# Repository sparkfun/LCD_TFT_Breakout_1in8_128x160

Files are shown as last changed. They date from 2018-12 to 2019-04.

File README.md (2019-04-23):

SparkFun LCD TFT Breakout 1.8" 128x160
========================================

LCD TFT Breakout 1.8" 128x160

[*LCD TFT Breakout 1.8" 128x160 (LCD-15143)*](https://www.sparkfun.com/products/15143)

A 128x160 color (18 bit!) TFT LCD display breakout with 4-wire SPI interface and microSD card holder. You can use this breakout to easily add visual display/interface capabilities to a project as well as all the storage you might need for multimedia files. 

Repository Contents
-------------------

* **/Documentation** - Data sheets, additional product information
* **/Hardware** - Eagle design files (.brd, .sch)
* **/Production** - Production panel files (.brd)

Documentation
--------------
* **[Library (Top Level)](https://github.com/sparkfun/SparkFun_HyperDisplay)** - Arduino library for general control of 2D visual interfaces.
* **[Library (Mid Level)](https://github.com/sparkfun/HyperDisplay_ILI9163C_ArduinoLibrary)** - Arduino library for all ILI9163 drivers (depends on top level).
* **[Library (Bottom Level)](https://github.com/sparkfun/HyperDisplay_KWH018ST01_4WSPI_ArduinoLibrary)** - Arduino library for the display module used in this breakout (depends on mid level).
* **[Hookup Guide](https://learn.sparkfun.com/tutorials/tft-lcd-breakout-18in-128x160-hookup-guide)** - Basic hookup guide for the LCD TFT Breakout 1.8" 128x160.
* **[SparkFun Fritzing repo](https://github.com/sparkfun/Fritzing_Parts)** - Fritzing diagrams for SparkFun products. 
<!-- * **[SparkFun 3D Model repo](https://github.com/sparkfun/3D_Models)** - 3D models of SparkFun products.  -->
<!-- * **[SparkFun Graphical Datasheets](https://github.com/sparkfun/Graphical_Datasheets)** -Graphical Datasheets for various SparkFun products. -->

Product Versions
----------------
* [LCD-15143](https://www.sparkfun.com/products/15143)

License Information
-------------------

This product is _**open source**_! 

Please review the LICENSE.md file for license information. 

If you have any questions or concerns on licensing, please contact technical support on our [SparkFun forums](https://forum.sparkfun.com/viewforum.php?f=152)

Distributed as-is; no warranty is given.

- Your friends at SparkFun.

_<COLLABORATION CREDIT>_

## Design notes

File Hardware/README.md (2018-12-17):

SparkFun <PRODUCT NAME> Design Files
=====================================

The .sch and .brd files hare are Eagle CAD schematic and PCB design files from SparkFun Electronics.
A freeware version of Eagle can be found [here](http://www.cadsoftusa.com/download-eagle/freeware/).

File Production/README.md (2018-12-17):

SparkFun <PRODUCT NAME> Production Files
=========================================

These are the production files SparkFun uses for printing PCBs.

License Information
-------------------
This product is open source! 

The hardware is released under [Creative Commons ShareAlike 4.0 International](https://creativecommons.org/licenses/by-sa/4.0/).

Please use, reuse, and modify these files as you see fit. Please maintain attribution to SparkFun Electronics and release anything derivative under the same license.

Distributed as-is; no warranty is given.

- Your friends at SparkFun.

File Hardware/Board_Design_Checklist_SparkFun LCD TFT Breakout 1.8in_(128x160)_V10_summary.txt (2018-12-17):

1) Are the part libraries consistent with eagle github repo? [NO]
comment: No. I haven't added the display to the libraries because I'm not sure where to put it, besides the part on the board is an FPC connector, not the display itself. I did add the FPC connector under the 40 position connector in the connectors library. Also there is one footprint that is just a custom solder position for the user so I'm not sure if that goes in the library

2) Have you verified that the BOM in Sparkle is accurate (also checking for PROD_ID, NAME, VALUE, PREFIX)? [NO]
comment: No Sparkle product yet... 

3) Do V-Scored edges have a 50 mil border free of pads and parts (to prevent cracking on separation)? [NO]
comment: Nearly... but I want the FPC connector to be right up at the edge of one vscore so that one violates this rule

4) Are all QFN components with 6 or more leads 75 percent pasted on lead pads? (May be contended depending on performance) [NO]
comment: They're closer to 80-90% pasted

5) Is there a correct version number in the copper (aligned properly with the edge of the PCB)? [NO]
comment: I couldn't fit it right on the edge, but it's close ish

6) Are all PTHs (aka connectors) clearly labeled with their purpose on both sides of the board? [NO]
comment: No, bottom side is unlabeled due to space constraints

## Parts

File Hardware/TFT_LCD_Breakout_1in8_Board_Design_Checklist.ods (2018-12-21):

SECTION | CHECK | STATUS | DEPENDANCY | CORRECT ANSWER | USER | USER-ANSWER | COMMENT | WIKI_LINK
Macro | is_revision | 0
Macro | has_pth | 0
Macro | has_i2c | 0
Macro | has_SPI | 0
Macro | has_1x6_ftdi_header | 0
Macro | has_jumpers | 0
Macro | has_leds | 0
Macro | has_vreg | 0
Macro | has_QFN | 0
Macro | has_SS | 0
Macro | has_multi_sheet | 0
Macro | is_kit | 0
Macro | has_serial | 0
Macro | is_4layer | 0
Macro | has_milling | 0
Macro | has_switchorbutton | 0
Macro | has_collaboration | 0
General | Are the part libraries consistent with eagle github repo? | YES |  | YES
Schematic | Is the proper frame with CC attribution used? | YES |  | YES
Schematic | Are all schematic objects inside the frame? | YES |  | YES
Schematic | Is there a SparkFun Logo? | YES |  | YES
Schematic | Is there an OSHW logo? | YES |  | YES
Schematic | Is proper attribution given to the original designer? | YES |  | YES
Schematic | Is "Revised by: " and the reviser's name present? | N/A | 2 | YES
Schematic | Are NET labels the correct FLAG type? | YES |  | YES
Schematic | Have all nets been drawn straight out from pin connections at least one grid space? | YES |  | YES
Schematic | Are all net lines 0.006 inch? | YES |  | YES
Schematic | Are there any 4-way junctions? | NO |  | NO
Schematic | Are junction dots used for all 3-wire connections? | YES |  | YES
Schematic | Are the fiducials in the lower right corner? | YES |  | YES
Schematic | Are the standoffs in the lower right corner? | YES |  | YES
Schematic | Are dashed grey lines ('info' eagle layer 97) used to clearly separate different areas? | YES |  | YES
Schematic | Is the version number correct? | YES |  | YES
Schematic | Is the version number included on all sheets? | YES | 12 | YES
Schematic | Do all GND connections use the GND symbol (oriented downward)? | YES |  | YES
Schematic | Do all VCC connections use the VCC symbol (oriented upward)? | YES |  | YES
Schematic | Is the VCC range clearly labeled? | YES |  | YES
Schematic | Are any jumpers labeled clearly by their function and possible settings? | YES | 7 | YES
Schematic | Are any appropriate warnings (voltage conversion, sensitive I/O) labeled? | YES |  | YES
Schematic | Are any notes of two versions of the board in the schematic (3.3V regulator vs 5V regulator)? | N/A |  | YES
Schematic | Do any part names have '/.~' in them? (Multiple sheets) | NO | 12 | NO
Schematic | Have you verified that the BOM in Sparkle is accurate (also checking for PROD_ID, NAME, VALUE, PREFIX)? | YES |  | YES
Schematic | Do any parts have unnecessary values (Eagle has autoset the package as the value)? | NO |  | NO
Schematic | Regarding the voltage regulator, is the input on the LEFT, and the output on the RIGHT? | YES | 9 | YES
Schematic | Is the I2C address in the schematic? | N/A | 4 | YES
Schematic | Is the I2C pin order correct (GND/VCC/SDA/CLK) and did you consider using a Qwiic connector? | N/A | 4 | YES |  |  |  | https://wiki.sparkfun.com/index.php?title=Eagle_Rules#Pin_Out.2FConnection_Orientation
Schematic | Is the I2C pull-up resistor isolation jumper present? | N/A | 4 | YES |  |  |  | https://wiki.sparkfun.com/index.php?title=Eagle_Rules#Component_Placement
Schematic | Is the SPI pull-up resistor for Chip Select present? | YES | 5 | YES |  |  |  | https://wiki.sparkfun.com/index.php?title=Eagle_Rules#Component_Placement
Schematic | Is the MISO tri-state buffer included? | NO | 5 | YES |  |  |  | https://wiki.sparkfun.com/index.php?title=Eagle_Rules#Component_Placement
Board | If this is a Qwiic board, does it follow the design guidelines for Qwiic boards in the Wiki? | N/A | 4 | YES |  |  |  | https://wiki.sparkfun.com/index.php?title=Qwiic_Standard
Board | If this board is not branded as a Qwicc board, but contains a Qwiic connector, is the connector labeled with “QWIIC” text silk? | N/A | 4
Board | Are the inner layers on the correct eagle layers? (2 and 15) | N/A | 15 | YES |  |  |  | https://wiki.sparkfun.com/index.php?title=Eagle_Rules#Board_Creation.2C_Outline
Board | Does your 4 layer board include '1' '2' '3' '4' in the copper of each layer? | N/A | 15 | YES |  |  |  | https://wiki.sparkfun.com/index.php?title=Eagle_Rules#Board_Creation.2C_Outline
Board | Is the bottom left corner board dimensions at 0,0? | YES |  | YES |  |  |  | https://wiki.sparkfun.com/index.php?title=Eagle_Rules#Board_Creation.2C_Outline
Board | Is the board dimension outline correct thickness? (0.008 inch) | YES |  | YES |  |  |  | https://wiki.sparkfun.com/index.php?title=Eagle_Rules#Board_Creation.2C_Outline
Board | If this requires very precise dimensions (e.g. USB stick), did you consider GP's tolerances? (dimension=5mils, Vscore=10mils) | N/A |  |  |  |  |  | https://wiki.sparkfun.com/index.php?title=Eagle_Rules#Fab_house_Tolerances
Board | Are 0.1 inch headers lined up on 0.1 inch grid? | YES |  | YES |  |  |  | https://wiki.sparkfun.com/index.php?title=Eagle_Rules#Board_Creation.2C_Outline
Board | Are opposing 0.1 inch headers spaced to fit into a breadboard? | N/A |  | YES |  |  |  | https://wiki.sparkfun.com/index.php?title=Eagle_Rules#Board_Creation.2C_Outline
Board | Do all testpoints have a separation of at least 0.1 inch (preferably placed on a 0.05 inch grid)? | YES |  | YES |  |  |  | https://wiki.sparkfun.com/index.php?title=Eagle_Rules#Board_Creation.2C_Outline
Board | Does the board have standoffs? | YES |  | YES |  |  |  | https://wiki.sparkfun.com/index.php?title=Eagle_Rules#Board_Creation.2C_Outline
Board | Can standoffs/screws be used clear of other parts? | YES |  | YES |  |  |  | https://wiki.sparkfun.com/index.php?title=Eagle_Rules#Board_Creation.2C_Outline
Board | Is the FTDI connector accessible (do neighboring parts allow enough space to clear each side)? | N/A | 6 | YES |  |  |  | https://wiki.sparkfun.com/index.php?title=Eagle_Rules#Pin_Out.2FConnection_Orientation
Board | Is the FTDI connector oriented so the FTDI breakout can be slid on properly (IC side up, header side down)? | N/A | 6 | YES |  |  |  | https://wiki.sparkfun.com/index.php?title=Eagle_Rules#Pin_Out.2FConnection_Orientation
Board | Are vias tented correctly? | YES |  | YES |  |  |  | https://wiki.sparkfun.com/index.php?title=Eagle_Rules#Trace_Routing.2C_Polygon_Pours.2C_and_Vias
Board | If possible, are all overhanging parts on the same edge of the board (this helps with panelization)? | N/A |  | YES |  |  |  | https://wiki.sparkfun.com/index.php?title=Eagle_Rules#Pin_Out.2FConnection_Orientation
Board | If this design requires special ordering or production assembly instructions, have the symbols/packages been added with notes? (PCB thickness, humidity sensitivity, etc.) | YES |  | YES
Board | Are any vias intended to be used as PTH headers (they shouldn't be)? | NO |  | NO |  |  |  | https://wiki.sparkfun.com/index.php?title=Eagle_Rules#Trace_Routing.2C_Polygon_Pours.2C_and_Vias
Board | Is the LED color standard followed? (red for power, blue for STAT, green for TX, yellow for RX) | YES | 8 | YES |  |  |  | https://wiki.sparkfun.com/index.php?title=Eagle_Rules#Component_Placement
Board | Do parts that need selective solder have a planned nozzle path on layer 48? (valid widths: 0.178", 0,263", 0.354") | N/A | 11 | YES |  |  |  | https://wiki.sparkfun.com/index.php?title=Eagle_Rules#Selective_Soldering
Board | As best as possible, do all SMD pads have only 1 trace entering the pad? | YES |  | YES |  |  |  | https://wiki.sparkfun.com/index.php?title=Eagle_Rules#PCB_Layout
Board | Are there any natural bridges on SMT components? | NO |  | NO |  |  |  | https://wiki.sparkfun.com/index.php?title=Eagle_Rules#PCB_Layout
Board | Do V-Scored edges have a 50 mil border free of pads and parts (to prevent cracking on separation)? | YES |  | YES
Board | Is the direction of TX/RX serial connections correct? | N/A | 14 | YES
Board | Are the TX/RX pins of the FTDI properly connected? | N/A | 6 | YES
Board | Is trace routing up to spec? (to/from center-points, straight lines, 45 angles, 'T' intersections, no right angles or acid traps) | YES |  | YES |  |  |  | https://wiki.sparkfun.com/index.php?title=Eagle_Rules#PCB_Layout
Board | For thermal considerations, are traces routed away from the component, with symmetrical routing? | YES | 10 | YES
Board | Do all footprints pass 1:1 check? (Applies mostly to new components) | YES |  | YES
Board | Are all QFN components with 6 or more leads 75 percent pasted on lead pads? (May be contended depending on performance) | YES | 10 | YES |  |  |  | https://wiki.sparkfun.com/index.php?title=Eagle_Rules#Footprints.2FPackages
Board | Are center pad cream apertures properly reduced? (50-75% paste is good) | N/A | 10 | YES |  |  |  | https://wiki.sparkfun.com/index.php?title=Eagle_Rules#Footprints.2FPackages
Board | Is there solder mask between pads on of 11 mil separation and greater? | NO |  | YES |  |  |  | https://wiki.sparkfun.com/index.php?title=Eagle_Rules#Fab_house_Tolerances
Board | Is there a correct version number in the copper (aligned properly with the edge of the PCB)? | YES |  | YES
Board | Are there fiducials on both the TOP and BOTTOM of the board? | YES |  | YES
Board | Does it pass DRC with top/bottom keepout layers on? | YES |  | YES
Board | If there are any DRC errors, have they all been approved? | YES |  | YES
Board | Are there airwires after ratsnest? | NO |  | NO
Board | Are all KIT PTH parts on the correct side with correct masking (e.g. the TSTOP or BSTOP expose the correct side) | N/A | 13 | YES
Documentation | Is there a note for a 4-layer board (on tDOCU)? | N/A | 15 | YES
Documentation | Do all packages have NAME and VALUE? | YES |  | YES
Documentation | Is there a note for a board thickness other than 0.63 inch? | N/A
Documentation | Are measurements included for outer dimension and standoffs (Eagle layer 47)? | YES |  | YES
Documentation | Are the board dimensions on 0.05 inch or 0.01 inch grid? | YES |  | YES
Documentation | Are routed-out areas labeled 'ROUTE OUT' (on dimension)? | YES | 16 | YES
Documentation | Is the CC/Design By included in tDocu? | YES |  | YES
Documentation | Is the designer name included in tDocu? | YES |  | YES
Documentation | Is 'Revised by:' and 'Revisor Name' included in tDocu? | N/A | 2 | YES
Silkscreen/Labeling | Is the name of the board on the board? | YES |  | YES |  |  |  | https://wiki.sparkfun.com/index.php?title=Eagle_Rules#PCB_Silk
Silkscreen/Labeling | Do all footprints have 0.008 inch silk footprint? | YES |  | YES
Silkscreen/Labeling | Are all LEDs labeled with their purpose? | YES | 8 | YES
Silkscreen/Labeling | Are all PTHs (aka connectors) clearly labeled with their purpose on both sides of the board? | YES |  | YES
Silkscreen/Labeling | Are battery terminals labeled +/- correctly? | N/A |  | YES
Silkscreen/Labeling | Are all jumpers labeled? | YES | 7 | YES
Silkscreen/Labeling | If it is a 3-way jumper, is there a label on each side of the jumper? | N/A | 7 | YES
Silkscreen/Labeling | Are all switches/buttons labeled properly? | N/A | 17 | YES
Silkscreen/Labeling | Are active low pins labeled clearly? | YES |  | YES
Silkscreen/Labeling | Are all labels lined up properly? | YES |  | YES
Silkscreen/Labeling | Is all text at least 0.032 inch, 15 percent radio, and vector? | YES |  | YES
Silkscreen/Labeling | Does the FTDI connector have BLK/GRN labeled correctly? | N/A | 6 | YES
Silkscreen/Labeling | Do all components have polarity or pin 1 labeled? | YES |  | YES
Silkscreen/Labeling | Is the polarity label outside of the package for visibility after part population? | YES |  | YES
Silkscreen/Labeling | Are there check labels for different versions of the board (3.3V vs 5V)? | N/A |  | YES
Silkscreen/Labeling | Is the SparkFun Logo on the board? | YES |  | YES
Silkscreen/Labeling | Is the OSHW logo on the board? | YES |  | YES
Silkscreen/Labeling | Is the firmware opensource? If not, did you omit the OSHW Logo? | YES | 18 | YES
Silkscreen/Labeling | Is any silkscreen overlaid on vias? | YES |  | NO
Silkscreen/Labeling | Is there a URL for any kits or unique boards? | N/A
Special | Are dimension lines properly spaced for V-scoring (lines on a 0.020” center-to-center spacing)? | YES
Special | On white solder mask pcbs, is there any solder mask between leads on large SMT components? | N/A
Special | Are axes labeled correctly? | N/A
Special | Are there warning labels for high voltage areas? | N/A
END | Thanks for flying with us. Have a great day!! | NO

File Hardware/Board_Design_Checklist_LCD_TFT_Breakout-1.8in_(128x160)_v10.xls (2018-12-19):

SECTION | CHECK | STATUS | DEPENDANCY | CORRECT ANSWER | USER | USER-ANSWER | COMMENT | WIKI_LINK
Macro | is_revision | 0
Macro | has_pth | 1
Macro | has_i2c | 0
Macro | has_SPI | 1
Macro | has_1x6_ftdi_header | 0
Macro | has_jumpers | 0
Macro | has_leds | 0
Macro | has_vreg | 0
Macro | has_QFN | 1
Macro | has_SS | 0
Macro | has_multi_sheet | 0
Macro | is_kit | 0
Macro | has_serial | 0
Macro | is_4layer | 0
Macro | has_milling | 1
Macro | has_switchorbutton | 0
Macro | has_collaboration | 0
General | Are the part libraries consistent with eagle github repo? |  |  | YES | owen.lyke | YES
Schematic | Is the proper frame with CC attribution used? |  |  | YES | owen.lyke | YES
Schematic | Are all schematic objects inside the frame? |  |  | YES | owen.lyke | YES
Schematic | Is there a SparkFun Logo? |  |  | YES | owen.lyke | YES
Schematic | Is there an OSHW logo? |  |  | YES | owen.lyke | YES
Schematic | Is proper attribution given to the original designer? |  |  | YES | owen.lyke | YES
Schematic | Is "Revised by: " and the reviser's name present? |  | 2 | YES | owen.lyke | *n/a*
Schematic | Are NET labels the correct FLAG type? |  |  | YES | owen.lyke | YES
Schematic | Have all nets been drawn straight out from pin connections at least one grid space? |  |  | YES | owen.lyke | YES
Schematic | Are all net lines 0.006 inch? |  |  | YES | owen.lyke | YES
Schematic | Are there any 4-way junctions? |  |  | NO | owen.lyke | NO
Schematic | Are junction dots used for all 3-wire connections? |  |  | YES | owen.lyke | YES
Schematic | Are the fiducials in the lower right corner? |  |  | YES | owen.lyke | YES
Schematic | Are the standoffs in the lower right corner? |  |  | YES | owen.lyke | YES
Schematic | Are dashed grey lines ('info' eagle layer 97) used to clearly separate different areas? |  |  | YES | owen.lyke | YES
Schematic | Is the version number correct? |  |  | YES | owen.lyke | YES | Yes. Changed to v03 since this is now a prototype and there were 2 protos before with SparkX
Schematic | Is the version number included on all sheets? |  | 12 | YES | owen.lyke | *n/a*
Schematic | Do all GND connections use the GND symbol (oriented downward)? |  |  | YES | owen.lyke | YES
Schematic | Do all VCC connections use the VCC symbol (oriented upward)? |  |  | YES | owen.lyke | YES
Schematic | Is the VCC range clearly labeled? |  |  | YES | owen.lyke | YES
Schematic | Are any jumpers labeled clearly by their function and possible settings? |  | 7 | YES | owen.lyke | *n/a*
Schematic | Are any appropriate warnings (voltage conversion, sensitive I/O) labeled? |  |  | YES | owen.lyke | n/a
Schematic | Are any notes of two versions of the board in the schematic (3.3V regulator vs 5V regulator)? |  |  | YES | owen.lyke | n/a
Schematic | Do any part names have '/.~' in them? (Multiple sheets) |  | 12 | NO | owen.lyke | *n/a*
Schematic | Have you verified that the BOM in Sparkle is accurate (also checking for PROD_ID, NAME, VALUE, PREFIX)? |  |  | YES | owen.lyke | YES
Schematic | Do any parts have unnecessary values (Eagle has autoset the package as the value)? |  |  | NO | owen.lyke | NO
Schematic | Regarding the voltage regulator, is the input on the LEFT, and the output on the RIGHT? |  | 9 | YES | owen.lyke | *n/a*
Schematic | Is the I2C address in the schematic? |  | 4 | YES | owen.lyke | *n/a*
Schematic | Is the I2C pin order correct (GND/VCC/SDA/CLK) and did you consider using a Qwiic connector? |  | 4 | YES | owen.lyke | *n/a* |  | https://wiki.sparkfun.com/index.php?title=Eagle_Rules#Pin_Out.2FConnection_Orientation
Schematic | Is the I2C pull-up resistor isolation jumper present? |  | 4 | YES | owen.lyke | *n/a* |  | https://wiki.sparkfun.com/index.php?title=Eagle_Rules#Component_Placement
Schematic | Is the SPI pull-up resistor for Chip Select present? |  | 5 | YES | owen.lyke | YES |  | https://wiki.sparkfun.com/index.php?title=Eagle_Rules#Component_Placement
Schematic | Is the MISO tri-state buffer included? |  | 5 | YES | owen.lyke | NO |  | https://wiki.sparkfun.com/index.php?title=Eagle_Rules#Component_Placement
Board | If this is a Qwiic board, does it follow the design guidelines for Qwiic boards in the Wiki? |  | 4 | YES | owen.lyke | *n/a* |  | https://wiki.sparkfun.com/index.php?title=Qwiic_Standard
Board | If this board is not branded as a Qwicc board, but contains a Qwiic connector, is the connector labeled with “QWIIC” text silk? |  | 4 |  | owen.lyke | NO
Board | Are the inner layers on the correct eagle layers? (2 and 15) |  | 15 | YES | owen.lyke | *n/a* |  | https://wiki.sparkfun.com/index.php?title=Eagle_Rules#Board_Creation.2C_Outline
Board | Does your 4 layer board include '1' '2' '3' '4' in the copper of each layer? |  | 15 | YES | owen.lyke | *n/a* |  | https://wiki.sparkfun.com/index.php?title=Eagle_Rules#Board_Creation.2C_Outline
Board | Is the bottom left corner board dimensions at 0,0? |  |  | YES | owen.lyke | YES |  | https://wiki.sparkfun.com/index.php?title=Eagle_Rules#Board_Creation.2C_Outline
Board | Is the board dimension outline correct thickness? (0.008 inch) |  |  | YES | owen.lyke | YES |  | https://wiki.sparkfun.com/index.php?title=Eagle_Rules#Board_Creation.2C_Outline
Board | If this requires very precise dimensions (e.g. USB stick), did you consider GP's tolerances? (dimension=5mils, Vscore=10mils) |  |  |  | owen.lyke | n/a |  | https://wiki.sparkfun.com/index.php?title=Eagle_Rules#Fab_house_Tolerances
Board | Are 0.1 inch headers lined up on 0.1 inch grid? |  |  | YES | owen.lyke | YES |  | https://wiki.sparkfun.com/index.php?title=Eagle_Rules#Board_Creation.2C_Outline
Board | Are opposing 0.1 inch headers spaced to fit into a breadboard? |  |  | YES | owen.lyke | n/a |  | https://wiki.sparkfun.com/index.php?title=Eagle_Rules#Board_Creation.2C_Outline
Board | Do all testpoints have a separation of at least 0.1 inch (preferably placed on a 0.05 inch grid)? |  |  | YES | owen.lyke | n/a |  | https://wiki.sparkfun.com/index.php?title=Eagle_Rules#Board_Creation.2C_Outline
Board | Does the board have standoffs? |  |  | YES | owen.lyke | YES |  | https://wiki.sparkfun.com/index.php?title=Eagle_Rules#Board_Creation.2C_Outline
Board | Can standoffs/screws be used clear of other parts? |  |  | YES | owen.lyke | YES |  | https://wiki.sparkfun.com/index.php?title=Eagle_Rules#Board_Creation.2C_Outline
Board | Is the FTDI connector accessible (do neighboring parts allow enough space to clear each side)? |  | 6 | YES | owen.lyke | *n/a* |  | https://wiki.sparkfun.com/index.php?title=Eagle_Rules#Pin_Out.2FConnection_Orientation
Board | Is the FTDI connector oriented so the FTDI breakout can be slid on properly (IC side up, header side down)? |  | 6 | YES | owen.lyke | *n/a* |  | https://wiki.sparkfun.com/index.php?title=Eagle_Rules#Pin_Out.2FConnection_Orientation
Board | Are vias tented correctly? |  |  | YES | owen.lyke | YES |  | https://wiki.sparkfun.com/index.php?title=Eagle_Rules#Trace_Routing.2C_Polygon_Pours.2C_and_Vias
Board | If possible, are all overhanging parts on the same edge of the board (this helps with panelization)? |  |  | YES | owen.lyke | YES |  | https://wiki.sparkfun.com/index.php?title=Eagle_Rules#Pin_Out.2FConnection_Orientation
Board | If this design requires special ordering or production assembly instructions, have the symbols/packages been added with notes? (PCB thickness, humidity sensitivity, etc.) |  |  | YES | owen.lyke | YES
Board | Are any vias intended to be used as PTH headers (they shouldn't be)? |  |  | NO | owen.lyke | NO |  | https://wiki.sparkfun.com/index.php?title=Eagle_Rules#Trace_Routing.2C_Polygon_Pours.2C_and_Vias
Board | Is the LED color standard followed? (red for power, blue for STAT, green for TX, yellow for RX) |  | 8 | YES | owen.lyke | *n/a* |  | https://wiki.sparkfun.com/index.php?title=Eagle_Rules#Component_Placement
Board | Do parts that need selective solder have a planned nozzle path on layer 48? (valid widths: 0.178", 0,263", 0.354") |  | 11 | YES | owen.lyke | *n/a* |  | https://wiki.sparkfun.com/index.php?title=Eagle_Rules#Selective_Soldering
Board | As best as possible, do all SMD pads have only 1 trace entering the pad? |  |  | YES | owen.lyke | YES |  | https://wiki.sparkfun.com/index.php?title=Eagle_Rules#PCB_Layout
Board | Are there any natural bridges on SMT components? |  |  | NO | owen.lyke | NO |  | https://wiki.sparkfun.com/index.php?title=Eagle_Rules#PCB_Layout
Board | Do V-Scored edges have a 50 mil border free of pads and parts (to prevent cracking on separation)? |  |  | YES | owen.lyke | NO | No, but it is a feature not a bug. The FPC connector is placed so that after the user breaks away half the board it will be on the edge
Board | Is the direction of TX/RX serial connections correct? |  | 14 | YES | owen.lyke | *n/a*
Board | Are the TX/RX pins of the FTDI properly connected? |  | 6 | YES | owen.lyke | *n/a*
Board | Is trace routing up to spec? (to/from center-points, straight lines, 45 angles, 'T' intersections, no right angles or acid traps) |  |  | YES | owen.lyke | YES |  | https://wiki.sparkfun.com/index.php?title=Eagle_Rules#PCB_Layout
Board | For thermal considerations, are traces routed away from the component, with symmetrical routing? |  | 10 | YES | owen.lyke | YES
Board | Do all footprints pass 1:1 check? (Applies mostly to new components) |  |  | YES | owen.lyke | YES
Board | Are all QFN components with 6 or more leads 75 percent pasted on lead pads? (May be contended depending on performance) |  | 10 | YES | owen.lyke | NO | No, txb0108 is more like 80-90% pasted. But it is tested | https://wiki.sparkfun.com/index.php?title=Eagle_Rules#Footprints.2FPackages
Board | Are center pad cream apertures properly reduced? (50-75% paste is good) |  | 10 | YES | owen.lyke | n/a |  | https://wiki.sparkfun.com/index.php?title=Eagle_Rules#Footprints.2FPackages
Board | Is there solder mask between pads on of 11 mil separation and greater? |  |  | YES | owen.lyke | YES |  | https://wiki.sparkfun.com/index.php?title=Eagle_Rules#Fab_house_Tolerances
Board | Is there a correct version number in the copper (aligned properly with the edge of the PCB)? |  |  | YES | owen.lyke | YES
Board | Are there fiducials on both the TOP and BOTTOM of the board? |  |  | YES | owen.lyke | YES
Board | Does it pass DRC with top/bottom keepout layers on? |  |  | YES | owen.lyke | YES
Board | If there are any DRC errors, have they all been approved? |  |  | YES | owen.lyke | YES | Yes, approved some stubs (used to connect GND beyond pour), overlaps (jumper w trace)
Board | Are there airwires after ratsnest? |  |  | NO | owen.lyke | NO
Board | Are all KIT PTH parts on the correct side with correct masking (e.g. the TSTOP or BSTOP expose the correct side) |  | 13 | YES | owen.lyke | *n/a*
Documentation | Is there a note for a 4-layer board (on tDOCU)? |  | 15 | YES | owen.lyke | *n/a*
Documentation | Do all packages have NAME and VALUE? |  |  | YES | owen.lyke | YES
Documentation | Is there a note for a board thickness other than 0.63 inch? |  |  |  | owen.lyke | n/a
Documentation | Are measurements included for outer dimension and standoffs (Eagle layer 47)? |  |  | YES | owen.lyke | YES
Documentation | Are the board dimensions on 0.05 inch or 0.01 inch grid? |  |  | YES | owen.lyke | YES
Documentation | Are routed-out areas labeled 'ROUTE OUT' (on dimension)? |  | 16 | YES | owen.lyke | YES
Documentation | Is the CC/Design By included in tDocu? |  |  | YES | owen.lyke | YES
Documentation | Is the designer name included in tDocu? |  |  | YES | owen.lyke | YES
Documentation | Is 'Revised by:' and 'Revisor Name' included in tDocu? |  | 2 | YES | owen.lyke | *n/a*
Silkscreen/Labeling | Is the name of the board on the board? |  |  | YES | owen.lyke | YES |  | https://wiki.sparkfun.com/index.php?title=Eagle_Rules#PCB_Silk
Silkscreen/Labeling | Do all footprints have 0.008 inch silk footprint? |  |  | YES | owen.lyke | YES
Silkscreen/Labeling | Are all LEDs labeled with their purpose? |  | 8 | YES | owen.lyke | *n/a*
Silkscreen/Labeling | Are all PTHs (aka connectors) clearly labeled with their purpose on both sides of the board? |  |  | YES | owen.lyke | YES
Silkscreen/Labeling | Are battery terminals labeled +/- correctly? |  |  | YES | owen.lyke | n/a
Silkscreen/Labeling | Are all jumpers labeled? |  | 7 | YES | owen.lyke | *n/a*
Silkscreen/Labeling | If it is a 3-way jumper, is there a label on each side of the jumper? |  | 7 | YES | owen.lyke | *n/a*
Silkscreen/Labeling | Are all switches/buttons labeled properly? |  | 17 | YES | owen.lyke | *n/a*
Silkscreen/Labeling | Are active low pins labeled clearly? |  |  | YES | owen.lyke | YES
Silkscreen/Labeling | Are all labels lined up properly? |  |  | YES | owen.lyke | YES
Silkscreen/Labeling | Is all text at least 0.032 inch, 15 percent radio, and vector? |  |  | YES | owen.lyke | YES
Silkscreen/Labeling | Does the FTDI connector have BLK/GRN labeled correctly? |  | 6 | YES | owen.lyke | *n/a*
Silkscreen/Labeling | Do all components have polarity or pin 1 labeled? |  |  | YES | owen.lyke | YES
Silkscreen/Labeling | Is the polarity label outside of the package for visibility after part population? |  |  | YES | owen.lyke | YES
Silkscreen/Labeling | Are there check labels for different versions of the board (3.3V vs 5V)? |  |  | YES | owen.lyke | n/a
Silkscreen/Labeling | Is the SparkFun Logo on the board? |  |  | YES | owen.lyke | YES
Silkscreen/Labeling | Is the OSHW logo on the board? |  |  | YES | owen.lyke | YES
Silkscreen/Labeling | Is the firmware opensource? If not, did you omit the OSHW Logo? |  | 18 | YES | owen.lyke | *n/a*
Silkscreen/Labeling | Is any silkscreen overlaid on vias? |  |  | NO | owen.lyke | YES
Silkscreen/Labeling | Is there a URL for any kits or unique boards? |  |  |  | owen.lyke | n/a
Special | Are dimension lines properly spaced for V-scoring (lines on a 0.020” center-to-center spacing)? |  |  |  | owen.lyke | YES
Special | On white solder mask pcbs, is there any solder mask between leads on large SMT components? |  |  |  | owen.lyke | n/a
Special | Are axes labeled correctly? |  |  |  | owen.lyke | n/a
Special | Are there warning labels for high voltage areas? |  |  |  | owen.lyke | n/a
END | Thanks for flying with us. Have a great day!! |  |  |  | owen.lyke | NO

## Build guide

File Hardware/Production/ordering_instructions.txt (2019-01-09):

panel size, 91x194mm
PCB thickness, 1.6mm
number of layers, 2
soldermask color, Red
silkscreen color, White
oz copper, 1oz
finish, HASL lead free
stencils, none
pcs per panel, 6

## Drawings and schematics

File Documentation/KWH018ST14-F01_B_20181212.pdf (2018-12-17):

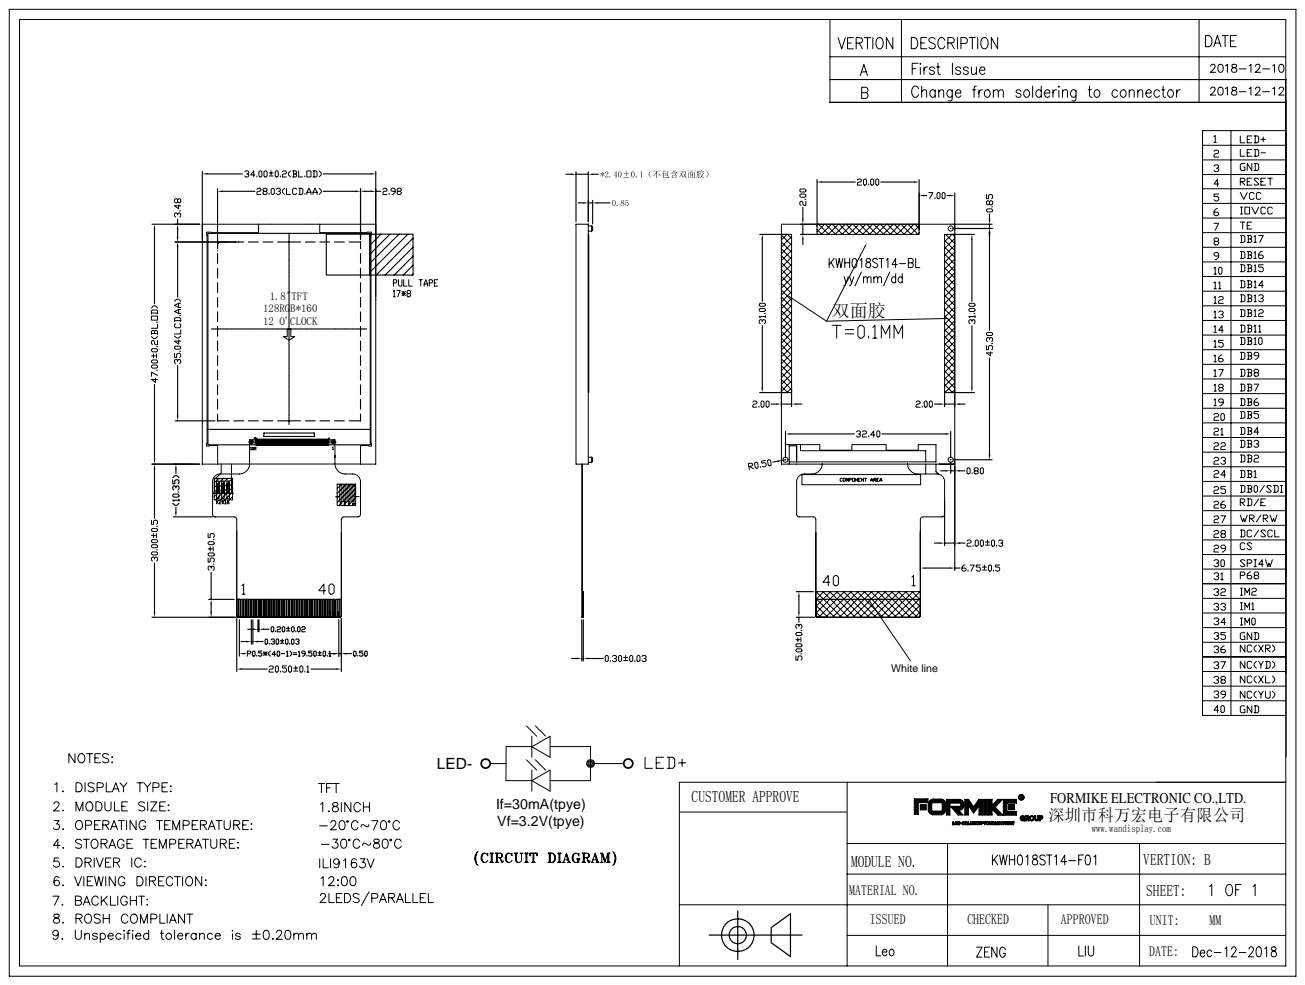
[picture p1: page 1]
VERTION: B; SHEET:; UNIT:; DATE:; CUSTOMER APPROVE; ISSUED; CHECKED; MODULE NO.; APPROVED; MATERIAL NO.; LED-; 1.8"TFT 128RGB*160 12 O'CLOCK; 双面胶; If=30mA(tpye); Vf=3.2V(tpye); www.wandisplay.com 深圳市科万宏电子有限公司; White line

FORMIKE ELECTRONIC CO.,LTD.

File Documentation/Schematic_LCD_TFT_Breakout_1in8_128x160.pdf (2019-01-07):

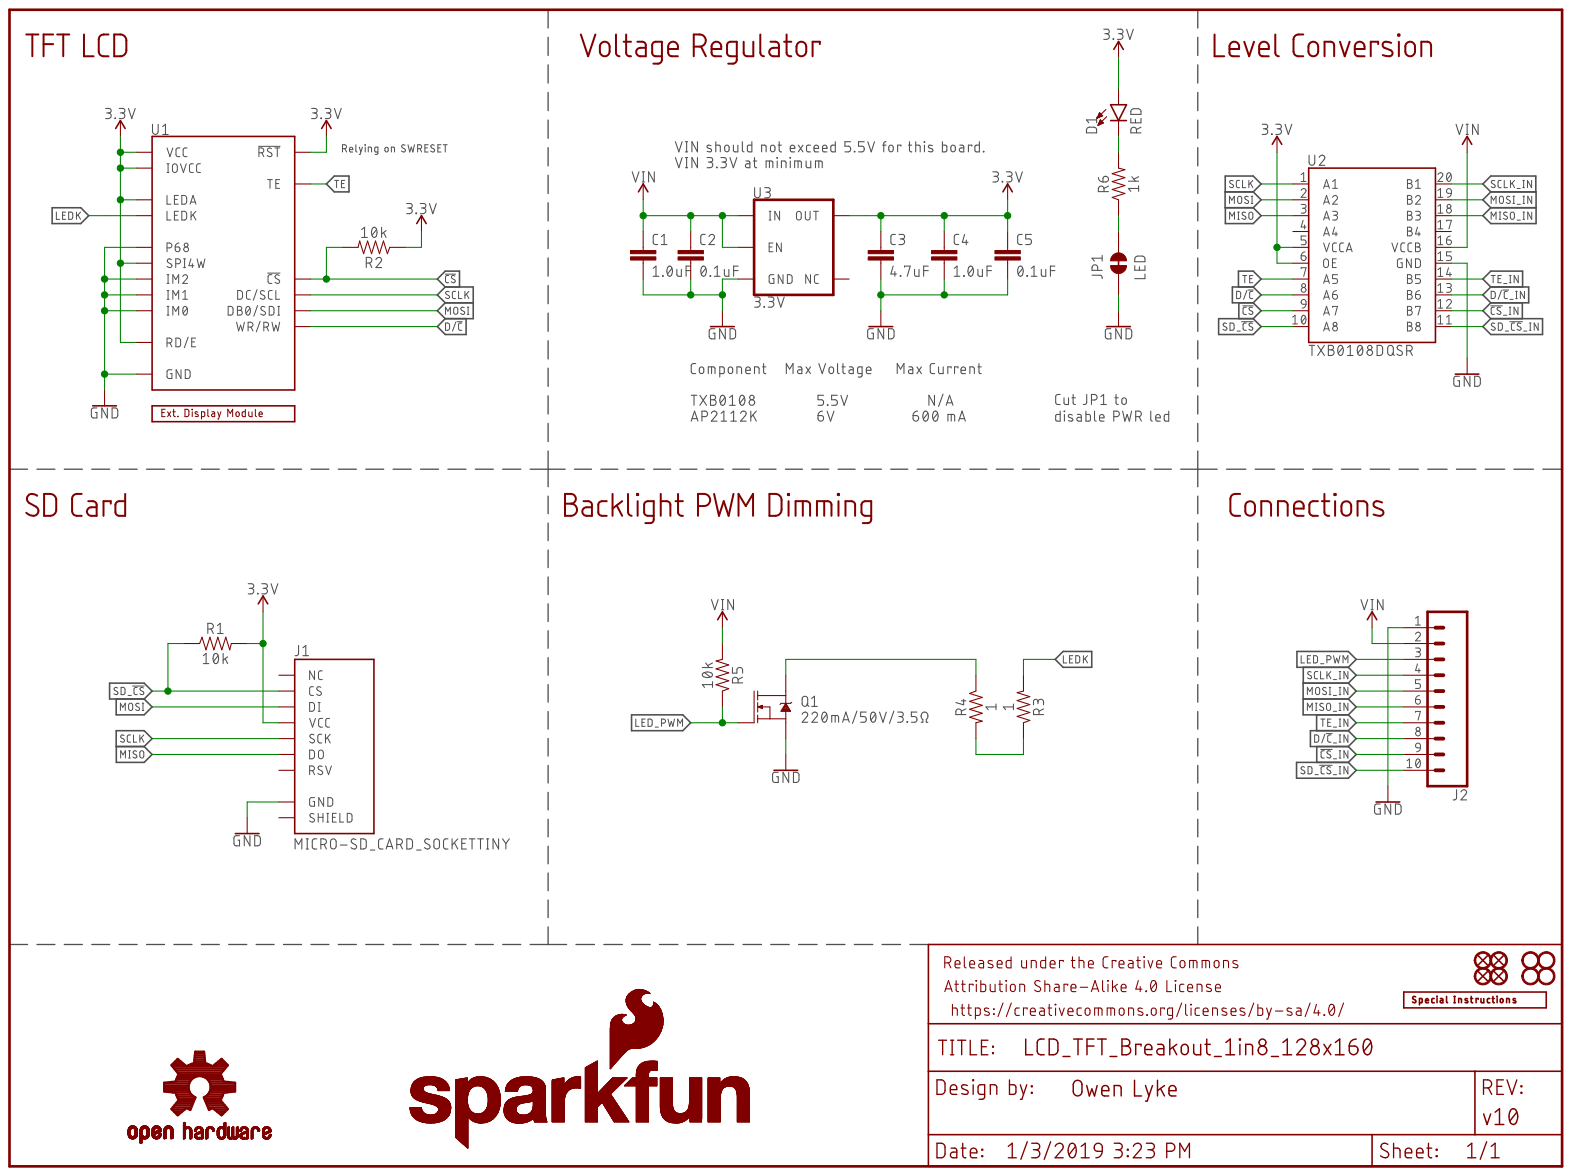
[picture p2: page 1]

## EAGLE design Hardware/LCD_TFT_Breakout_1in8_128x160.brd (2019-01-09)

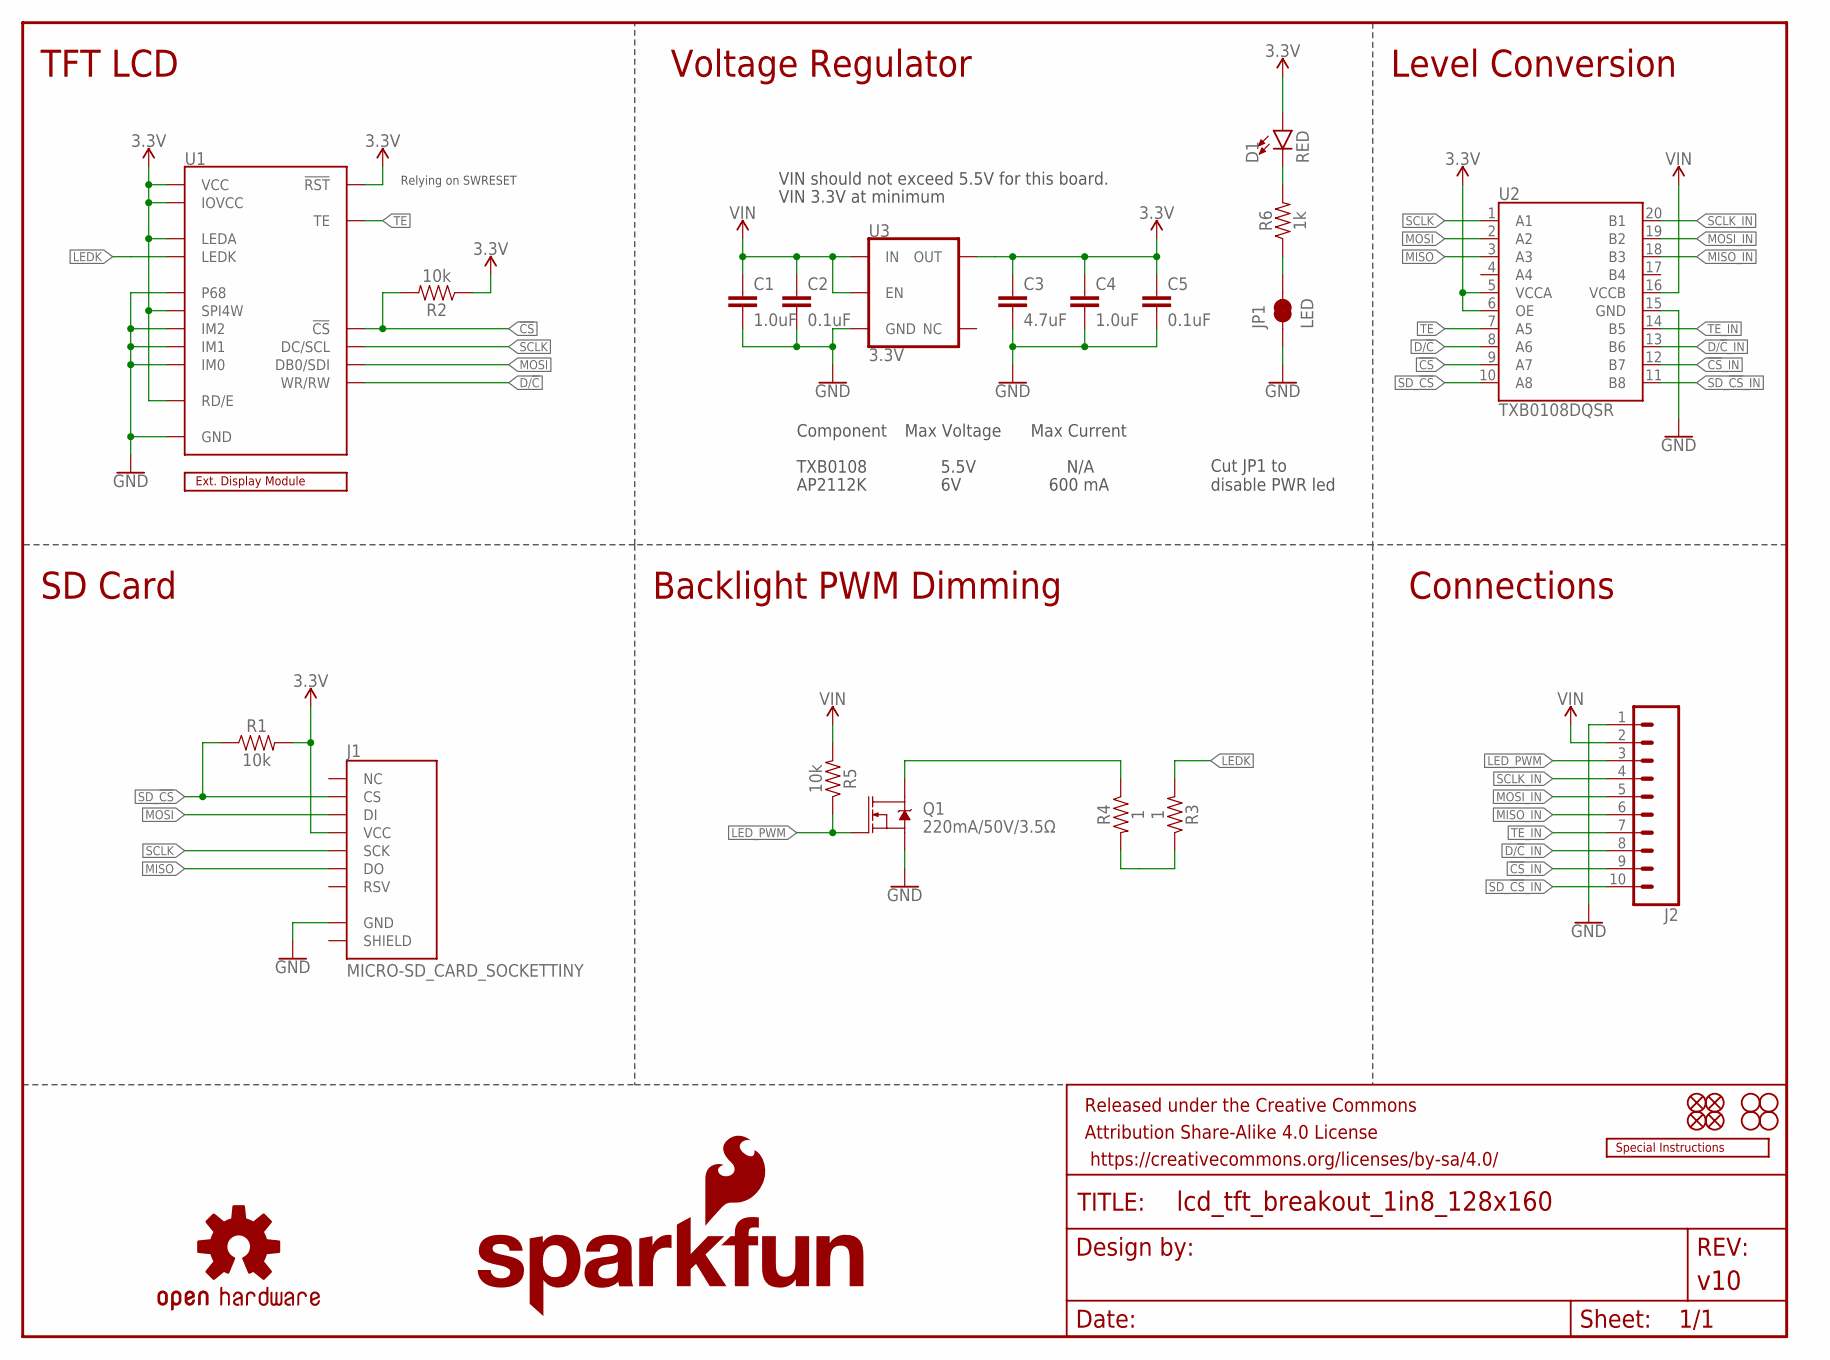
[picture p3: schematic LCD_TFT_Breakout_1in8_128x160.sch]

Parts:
C1, C4: 1.0uF; 0603
C2, C5: 0.1uF; 0603
C3: 4.7uF; 0603
D1: RED; LED-0603
FD1, FD2, FD3, FD4: FIDUCIAL1X2; FIDUCIAL-1X2
FRAME1: FRAME-LETTER; CREATIVE_COMMONS
H1, H2, H3, H4: STAND-OFF
J1: MICRO-SD_CARD_SOCKETTINY; MICROSD_TINY
J2: CONN_10NO_SILK_PTH_FEMALE; 1X10_NO_SILK
JP1: LED; SMT-JUMPER_2_NC_TRACE_SILK
LOGO1: SFE_LOGO_NAME_FLAME.3_INCH; SFE_LOGO_NAME_FLAME_.3
LOGO2: SPECIAL_INSTRUCTIONS-PRODUCTION; PRODUCTION_INSTRUCTIONS
LOGO3: OSHW-LOGOS; OSHW-LOGO-S
Q1: 220mA/50V/3.5Ω; SOT23-3
R1, R2, R5: 10k; 0603
R3, R4: 1; 0603
R6: 1k; 0603
U1: KWH018ST14-F01_4WSPI-BOTTOM; FPC05040-17204
U2: TXB0108DQSR; UFDFN-20
U3: 3.3V; SOT23-5
U$33: EXTERNAL_DISP-KWH018ST14-F01; KWH018ST14-F01_HOLES

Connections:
3.3V: C3.1, C4.1, C5.1, D1.A, J1.4 (VCC), R1.2, R2.1, U1.P$1 (LEDA), U1.P$4 (!RST), U1.P$5 (VCC), U1.P$6 (IOVCC), U1.P$26 (RD/E), U1.P$30 (SPI4W), U2.5 (VCCA), U2.6 (OE), U3.5 (OUT)
!CS: R2.2, U1.P$29 (!CS), U2.9 (A7)
!CS!_IN: J2.9, U2.12 (B7)
D/!C: U1.P$27 (WR/RW), U2.8 (A6)
D/!C!_IN: J2.8, U2.13 (B6)
GND: C1.2, C2.2, C3.2, C4.2, C5.2, J1.6 (GND), J2.1, JP1.1, Q1.2 (S), U1.P$3 (GND), U1.P$8 (GND), U1.P$9 (GND), U1.P$10 (GND), U1.P$11 (GND), U1.P$12 (GND), U1.P$13 (GND), U1.P$14 (GND), U1.P$15 (GND), U1.P$16 (GND), U1.P$17 (GND), U1.P$18 (GND), U1.P$19 (GND), U1.P$20 (GND), U1.P$21 (GND), U1.P$22 (GND), U1.P$23 (GND), U1.P$24 (GND), U1.P$31 (P68), U1.P$32 (IM2), U1.P$33 (IM1), U1.P$34 (IM0), U1.P$35 (GND), U1.P$40 (GND), U2.15 (GND), U3.2 (GND)
LEDK: R3.2, U1.P$2 (LEDK)
LED_PWM: J2.3, Q1.1 (G), R5.1
MISO: J1.7 (DO), U2.3 (A3)
MISO_IN: J2.6, U2.18 (B3)
MOSI: J1.3 (DI), U1.P$25 (DB0/SDI), U2.2 (A2)
MOSI_IN: J2.5, U2.19 (B2)
unnamed: D1.C, R6.2
unnamed: JP1.2, R6.1
unnamed: R3.1, R4.2
unnamed: Q1.3 (D), R4.1
SCLK: J1.5 (SCK), U1.P$28 (DC/SCL), U2.1 (A1)
SCLK_IN: J2.4, U2.20 (B1)
SD_!CS: J1.2 (CS), R1.1, U2.10 (A8)
SD_!CS!_IN: J2.10, U2.11 (B8)
TE: U1.P$7 (TE), U2.7 (A5)
TE_IN: J2.7, U2.14 (B5)
VIN: C1.1, C2.1, J2.2, R5.2, U2.16 (VCCB), U3.1 (IN), U3.3 (EN)

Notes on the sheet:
Voltage Regulator
Level Conversion
Backlight PWM Dimming
Relying on SWRESET
TFT LCD
Connections
SD Card
VIN should not exceed 5.5V for this board.
Component
Max Voltage
TXB0108
AP2112K
Max Current
600 mA
N/A
5.5V
Cut JP1 to disable PWR led
VIN 3.3V at minimum

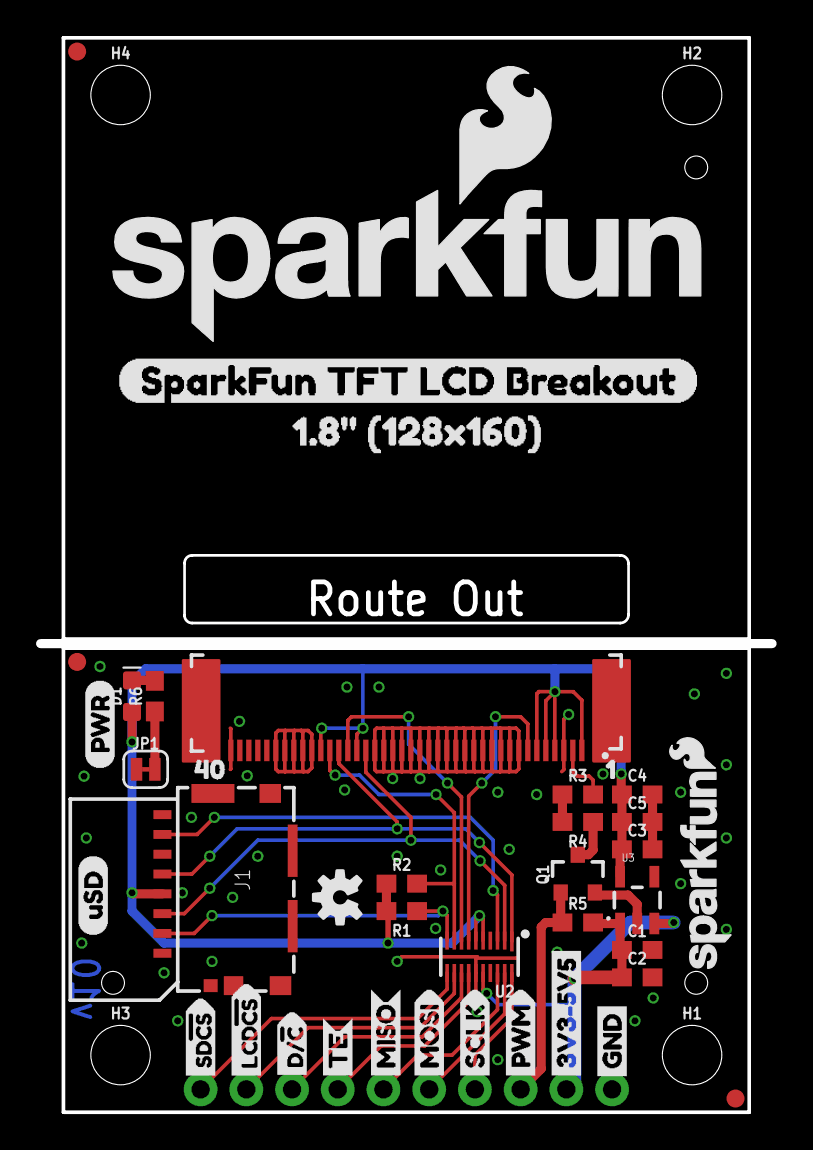
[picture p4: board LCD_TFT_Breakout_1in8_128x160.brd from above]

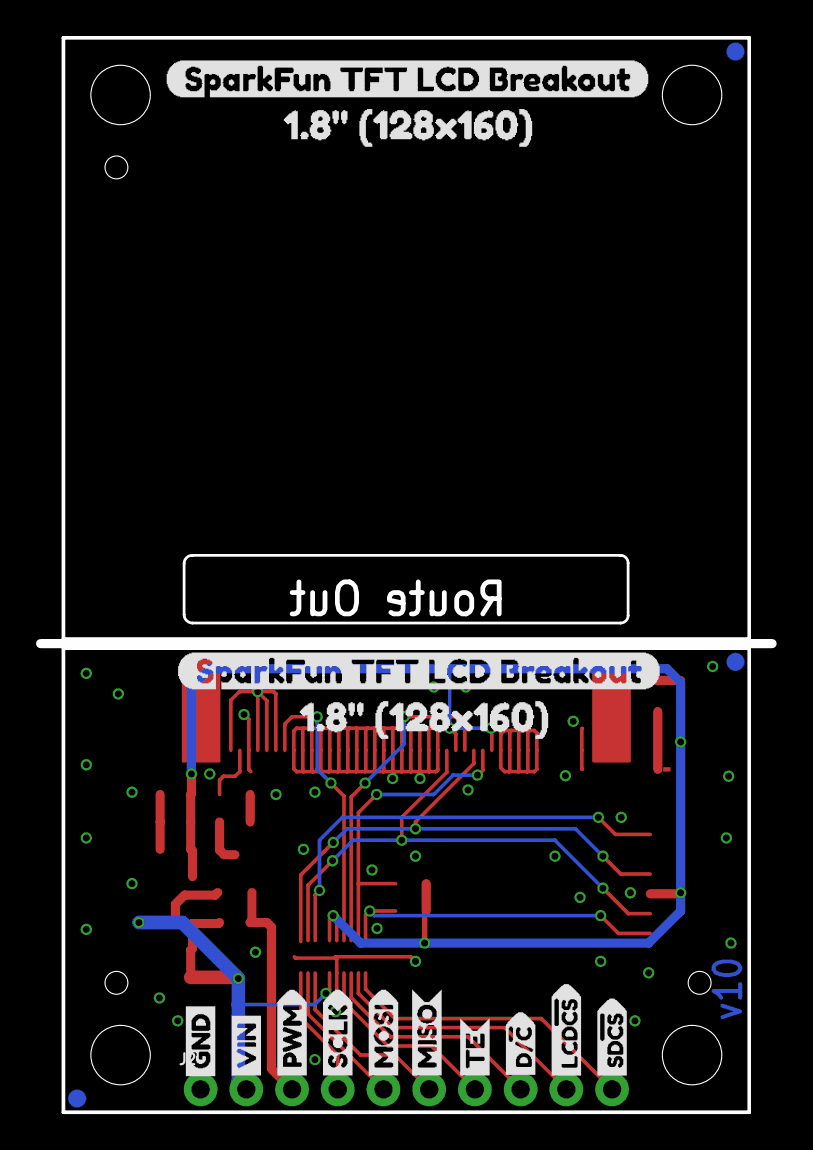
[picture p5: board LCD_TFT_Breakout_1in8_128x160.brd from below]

Board: 2 copper layers, 40.6 x 59.7 mm, 66 parts (19 on the bottom side), 23 nets.

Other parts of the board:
FD5, FD6: FIDUCIAL1X2; FIDUCIAL-1X2
U$1: 3V3#5V50
U$2: SFE_LOGO_NAME_.1
U$3: SFE_LOGO_FLAME_.1
U$4: USD2
U$5, U$6: LCD#CS1
U$7, U$25: D##C7
U$8, U$16: SD#CS0
U$9, U$32: GND0
U$10: VIN1
U$11, U$26: MISO3
U$12, U$27: MOSI2
U$13, U$28: SCLK4
U$14, U$29: TE5
U$15, U$30: PWM6
U$17: 10
U$18: PWR4
U$19: SPARKFUN_TFT_LCD_BREAKOUT1
U$20: 1#8#_#128X160#1
U$21, U$23: SPARKFUN_TFT_LCD_BREAKOUT2
U$22, U$24: 1#8#_#128X160#0
U$31: 401

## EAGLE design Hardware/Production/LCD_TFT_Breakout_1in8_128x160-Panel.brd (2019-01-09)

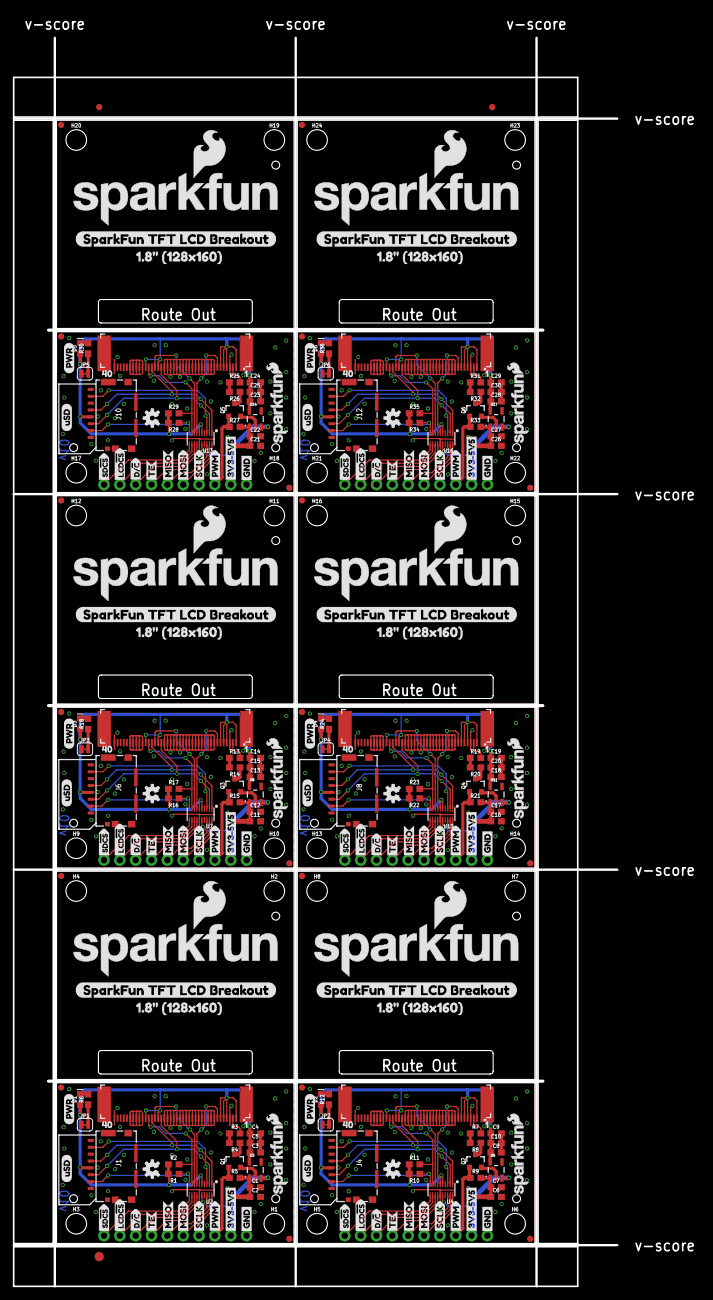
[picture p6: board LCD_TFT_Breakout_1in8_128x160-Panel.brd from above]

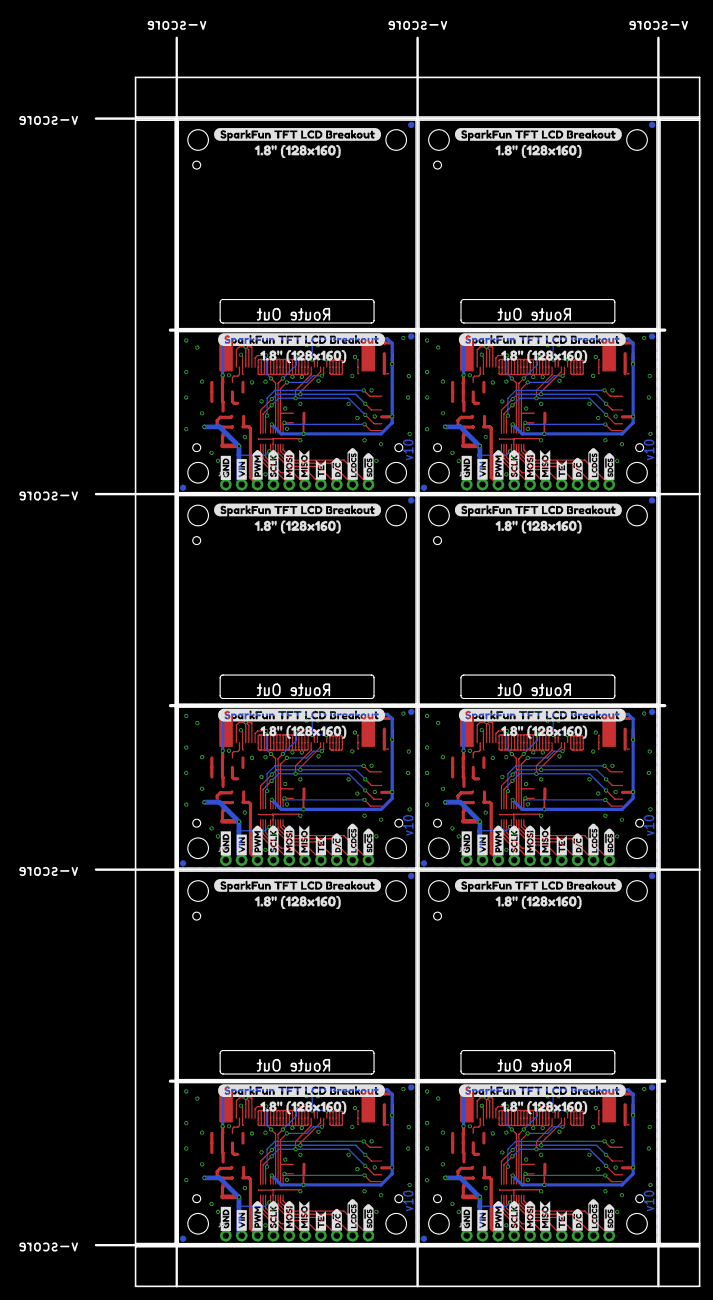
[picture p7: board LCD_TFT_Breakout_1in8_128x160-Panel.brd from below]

Board: 2 copper layers, 96.8 x 200.2 mm, 399 parts (114 on the bottom side), 138 nets.

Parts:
C1, C4, C7, C9, C12, C14, C17, C19, C22, C24, C27, C29: 1.0uF; 0603
C2, C5, C6, C10, C11, C15, C16, C20, C21, C25, C26, C30: 0.1uF; 0603
C3, C8, C13, C18, C23, C28: 4.7uF; 0603
D1, D2, D3, D4, D5, D6: RED; LED-0603
E$1, E$2: FIDUCIAL-1X2
E$3: FIDUCIAL-1.5X3
FD1, FD2, FD3, FD4, FD5, FD6, FD7, FD8, FD9, FD10, FD11, FD12, FD13, FD14, FD15, FD16, FD17, FD18, FD19, FD20, FD21, FD22, FD23, FD24, FD25, FD26, FD27, FD28, FD29, FD30, FD31, FD32, FD33, FD34, FD35, FD36: FIDUCIAL1X2; FIDUCIAL-1X2
FRAME1, FRAME2, FRAME3, FRAME4, FRAME5, FRAME6: FRAME-LETTER; CREATIVE_COMMONS
H1, H2, H3, H4, H5, H6, H7, H8, H9, H10, H11, H12, H13, H14, H15, H16, H17, H18, H19, H20, H21, H22, H23, H24: STAND-OFF
J1, J4, J6, J8, J10, J12: MICRO-SD_CARD_SOCKETTINY; MICROSD_TINY
J2, J3, J5, J7, J9, J11: 1X10_NO_SILK
JP1, JP2, JP3, JP4, JP5, JP6: LED; SMT-JUMPER_2_NC_TRACE_SILK
LOGO1, LOGO5, LOGO8, LOGO11, LOGO14, LOGO17: SFE_LOGO_NAME_FLAME.3_INCH; SFE_LOGO_NAME_FLAME_.3
LOGO2, LOGO4, LOGO7, LOGO10, LOGO13, LOGO16: SPECIAL_INSTRUCTIONS-PRODUCTION; PRODUCTION_INSTRUCTIONS
LOGO3, LOGO6, LOGO9, LOGO12, LOGO15, LOGO18: OSHW-LOGOS; OSHW-LOGO-S
Q1, Q2, Q3, Q4, Q5, Q6: 220mA/50V/3.5Ω; SOT23-3
R1, R2, R5, R9, R10, R11, R15, R16, R17, R21, R22, R23, R27, R28, R29, R33, R34, R35: 10k; 0603
R3, R4, R7, R8, R13, R14, R19, R20, R25, R26, R31, R32: 1; 0603
R6, R12, R18, R24, R30, R36: 1k; 0603
U1, U6, U9, U12, U15, U18: FPC05040-17204
U2, U4, U7, U10, U13, U16: TXB0108DQSR; UFDFN-20
U3, U5, U8, U11, U14, U17: 3.3V; SOT23-5
U$1, U$64, U$97, U$130, U$163, U$196: 3V3#5V50
U$2, U$34, U$67, U$100, U$133, U$166: SFE_LOGO_NAME_.1
U$3, U$35, U$68, U$101, U$134, U$167: SFE_LOGO_FLAME_.1
U$4, U$61, U$94, U$127, U$160, U$193: USD2
U$5, U$6, U$57, U$58, U$90, U$91, U$123, U$124, U$156, U$157, U$189, U$190: LCD#CS1
U$7, U$25, U$36, U$50, U$69, U$83, U$102, U$116, U$135, U$149, U$168, U$182: D##C7
U$8, U$16, U$59, U$60, U$92, U$93, U$125, U$126, U$158, U$159, U$191, U$192: SD#CS0
U$9, U$32, U$37, U$56, U$70, U$89, U$103, U$122, U$136, U$155, U$169, U$188: GND0
U$10, U$38, U$71, U$104, U$137, U$170: VIN1
U$11, U$26, U$39, U$51, U$72, U$84, U$105, U$117, U$138, U$150, U$171, U$183: MISO3
U$12, U$27, U$40, U$52, U$73, U$85, U$106, U$118, U$139, U$151, U$172, U$184: MOSI2
U$13, U$28, U$41, U$53, U$74, U$86, U$107, U$119, U$140, U$152, U$173, U$185: SCLK4
U$14, U$29, U$42, U$54, U$75, U$87, U$108, U$120, U$141, U$153, U$174, U$186: TE5
U$15, U$30, U$43, U$55, U$76, U$88, U$109, U$121, U$142, U$154, U$175, U$187: PWM6
U$17, U$65, U$98, U$131, U$164, U$197: 10
U$18, U$62, U$95, U$128, U$161, U$194: PWR4
U$19, U$44, U$77, U$110, U$143, U$176: SPARKFUN_TFT_LCD_BREAKOUT1
U$20, U$45, U$78, U$111, U$144, U$177: 1#8#_#128X160#1
U$21, U$23, U$46, U$48, U$79, U$81, U$112, U$114, U$145, U$147, U$178, U$180: SPARKFUN_TFT_LCD_BREAKOUT2
U$22, U$24, U$47, U$49, U$80, U$82, U$113, U$115, U$146, U$148, U$179, U$181: 1#8#_#128X160#0
U$31, U$66, U$99, U$132, U$165, U$198: 401
U$33, U$63, U$96, U$129, U$162, U$195: EXTERNAL_DISP-KWH018ST14-F01; KWH018ST14-F01_HOLES

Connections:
3.3V: C3.1, C4.1, C5.1, D1.A, J1.4, R1.2, R2.1, U1.P$1, U1.P$4, U1.P$5, U1.P$6, U1.P$26, U1.P$30, U2.5, U2.6, U3.5
3.3V1: C8.1, C9.1, C10.1, D2.A, J4.4, R10.2, R11.1, U4.5, U4.6, U5.5, U6.P$1, U6.P$4, U6.P$5, U6.P$6, U6.P$26, U6.P$30
3.3V2: C13.1, C14.1, C15.1, D3.A, J6.4, R16.2, R17.1, U7.5, U7.6, U8.5, U9.P$1, U9.P$4, U9.P$5, U9.P$6, U9.P$26, U9.P$30
3.3V3: C18.1, C19.1, C20.1, D4.A, J8.4, R22.2, R23.1, U10.5, U10.6, U11.5, U12.P$1, U12.P$4, U12.P$5, U12.P$6, U12.P$26, U12.P$30
3.3V4: C23.1, C24.1, C25.1, D5.A, J10.4, R28.2, R29.1, U13.5, U13.6, U14.5, U15.P$1, U15.P$4, U15.P$5, U15.P$6, U15.P$26, U15.P$30
3.3V5: C28.1, C29.1, C30.1, D6.A, J12.4, R34.2, R35.1, U16.5, U16.6, U17.5, U18.P$1, U18.P$4, U18.P$5, U18.P$6, U18.P$26, U18.P$30
!CS: R2.2, U1.P$29, U2.9
!CS1: R11.2, U4.9, U6.P$29
!CS2: R17.2, U7.9, U9.P$29
!CS3: R23.2, U10.9, U12.P$29
!CS4: R29.2, U13.9, U15.P$29
!CS5: R35.2, U16.9, U18.P$29
!CS!_IN: J2.9, U2.12
!CS!_IN1: J3.9, U4.12
!CS!_IN2: J5.9, U7.12
!CS!_IN3: J7.9, U10.12
!CS!_IN4: J9.9, U13.12
!CS!_IN5: J11.9, U16.12
D/!C: U1.P$27, U2.8
D/!C1: U4.8, U6.P$27
D/!C2: U7.8, U9.P$27
D/!C3: U10.8, U12.P$27
D/!C4: U13.8, U15.P$27
D/!C5: U16.8, U18.P$27
D/!C!_IN: J2.8, U2.13
D/!C!_IN1: J3.8, U4.13
D/!C!_IN2: J5.8, U7.13
D/!C!_IN3: J7.8, U10.13
D/!C!_IN4: J9.8, U13.13
D/!C!_IN5: J11.8, U16.13
GND: C1.2, C2.2, C3.2, C4.2, C5.2, J1.6, J2.1, JP1.1, Q1.2, U1.P$3, U1.P$8, U1.P$9, U1.P$10, U1.P$11, U1.P$12, U1.P$13, U1.P$14, U1.P$15, U1.P$16, U1.P$17, U1.P$18, U1.P$19, U1.P$20, U1.P$21, U1.P$22, U1.P$23, U1.P$24, U1.P$31, U1.P$32, U1.P$33, U1.P$34, U1.P$35, U1.P$40, U2.15, U3.2
GND1: C6.2, C7.2, C8.2, C9.2, C10.2, J3.1, J4.6, JP2.1, Q2.2, U4.15, U5.2, U6.P$3, U6.P$8, U6.P$9, U6.P$10, U6.P$11, U6.P$12, U6.P$13, U6.P$14, U6.P$15, U6.P$16, U6.P$17, U6.P$18, U6.P$19, U6.P$20, U6.P$21, U6.P$22, U6.P$23, U6.P$24, U6.P$31, U6.P$32, U6.P$33, U6.P$34, U6.P$35, U6.P$40
GND2: C11.2, C12.2, C13.2, C14.2, C15.2, J5.1, J6.6, JP3.1, Q3.2, U7.15, U8.2, U9.P$3, U9.P$8, U9.P$9, U9.P$10, U9.P$11, U9.P$12, U9.P$13, U9.P$14, U9.P$15, U9.P$16, U9.P$17, U9.P$18, U9.P$19, U9.P$20, U9.P$21, U9.P$22, U9.P$23, U9.P$24, U9.P$31, U9.P$32, U9.P$33, U9.P$34, U9.P$35, U9.P$40
GND3: C16.2, C17.2, C18.2, C19.2, C20.2, J7.1, J8.6, JP4.1, Q4.2, U10.15, U11.2, U12.P$3, U12.P$8, U12.P$9, U12.P$10, U12.P$11, U12.P$12, U12.P$13, U12.P$14, U12.P$15, U12.P$16, U12.P$17, U12.P$18, U12.P$19, U12.P$20, U12.P$21, U12.P$22, U12.P$23, U12.P$24, U12.P$31, U12.P$32, U12.P$33, U12.P$34, U12.P$35, U12.P$40
GND4: C21.2, C22.2, C23.2, C24.2, C25.2, J9.1, J10.6, JP5.1, Q5.2, U13.15, U14.2, U15.P$3, U15.P$8, U15.P$9, U15.P$10, U15.P$11, U15.P$12, U15.P$13, U15.P$14, U15.P$15, U15.P$16, U15.P$17, U15.P$18, U15.P$19, U15.P$20, U15.P$21, U15.P$22, U15.P$23, U15.P$24, U15.P$31, U15.P$32, U15.P$33, U15.P$34, U15.P$35, U15.P$40
GND5: C26.2, C27.2, C28.2, C29.2, C30.2, J11.1, J12.6, JP6.1, Q6.2, U16.15, U17.2, U18.P$3, U18.P$8, U18.P$9, U18.P$10, U18.P$11, U18.P$12, U18.P$13, U18.P$14, U18.P$15, U18.P$16, U18.P$17, U18.P$18, U18.P$19, U18.P$20, U18.P$21, U18.P$22, U18.P$23, U18.P$24, U18.P$31, U18.P$32, U18.P$33, U18.P$34, U18.P$35, U18.P$40
LEDK: R3.2, U1.P$2
LEDK1: R7.2, U6.P$2
LEDK2: R13.2, U9.P$2
LEDK3: R19.2, U12.P$2
LEDK4: R25.2, U15.P$2
LEDK5: R31.2, U18.P$2
LED_PWM: J2.3, Q1.1, R5.1
LED_PWM1: J3.3, Q2.1, R9.1
LED_PWM2: J5.3, Q3.1, R15.1
LED_PWM3: J7.3, Q4.1, R21.1
LED_PWM4: J9.3, Q5.1, R27.1
LED_PWM5: J11.3, Q6.1, R33.1
MISO: J1.7, U2.3
MISO1: J4.7, U4.3
MISO2: J6.7, U7.3
MISO3: J8.7, U10.3
MISO4: J10.7, U13.3
MISO5: J12.7, U16.3
MISO_IN: J2.6, U2.18
MISO_IN1: J3.6, U4.18
MISO_IN2: J5.6, U7.18
MISO_IN3: J7.6, U10.18
MISO_IN4: J9.6, U13.18
MISO_IN5: J11.6, U16.18
MOSI: J1.3, U1.P$25, U2.2
MOSI1: J4.3, U4.2, U6.P$25
MOSI2: J6.3, U7.2, U9.P$25
MOSI3: J8.3, U10.2, U12.P$25
MOSI4: J10.3, U13.2, U15.P$25
MOSI5: J12.3, U16.2, U18.P$25
MOSI_IN: J2.5, U2.19
MOSI_IN1: J3.5, U4.19
MOSI_IN2: J5.5, U7.19
MOSI_IN3: J7.5, U10.19
MOSI_IN4: J9.5, U13.19
MOSI_IN5: J11.5, U16.19
unnamed: D1.C, R6.2
unnamed: JP1.2, R6.1
unnamed: R3.1, R4.2
unnamed: Q2.3, R8.1
unnamed: Q1.3, R4.1
unnamed: D2.C, R12.2
unnamed: JP2.2, R12.1
unnamed: R7.1, R8.2
unnamed: Q3.3, R14.1
unnamed: D3.C, R18.2
unnamed: JP3.2, R18.1
unnamed: R13.1, R14.2
unnamed: Q4.3, R20.1
unnamed: D4.C, R24.2
unnamed: JP4.2, R24.1
unnamed: R19.1, R20.2
unnamed: Q5.3, R26.1
unnamed: D5.C, R30.2
unnamed: JP5.2, R30.1
unnamed: R25.1, R26.2
unnamed: Q6.3, R32.1
unnamed: D6.C, R36.2
unnamed: JP6.2, R36.1
unnamed: R31.1, R32.2
SCLK: J1.5, U1.P$28, U2.1
SCLK1: J4.5, U4.1, U6.P$28
SCLK2: J6.5, U7.1, U9.P$28
SCLK3: J8.5, U10.1, U12.P$28
SCLK4: J10.5, U13.1, U15.P$28
SCLK5: J12.5, U16.1, U18.P$28
SCLK_IN: J2.4, U2.20
SCLK_IN1: J3.4, U4.20
SCLK_IN2: J5.4, U7.20
SCLK_IN3: J7.4, U10.20
SCLK_IN4: J9.4, U13.20
SCLK_IN5: J11.4, U16.20
SD_!CS: J1.2, R1.1, U2.10
SD_!CS1: J4.2, R10.1, U4.10
SD_!CS2: J6.2, R16.1, U7.10
SD_!CS3: J8.2, R22.1, U10.10
SD_!CS4: J10.2, R28.1, U13.10
SD_!CS5: J12.2, R34.1, U16.10
SD_!CS!_IN: J2.10, U2.11
SD_!CS!_IN1: J3.10, U4.11
SD_!CS!_IN2: J5.10, U7.11
SD_!CS!_IN3: J7.10, U10.11
SD_!CS!_IN4: J9.10, U13.11
SD_!CS!_IN5: J11.10, U16.11
TE: U1.P$7, U2.7
TE1: U4.7, U6.P$7
TE2: U7.7, U9.P$7
TE3: U10.7, U12.P$7
TE4: U13.7, U15.P$7
TE5: U16.7, U18.P$7
TE_IN: J2.7, U2.14
TE_IN1: J3.7, U4.14
TE_IN2: J5.7, U7.14
TE_IN3: J7.7, U10.14
TE_IN4: J9.7, U13.14
TE_IN5: J11.7, U16.14
VIN: C1.1, C2.1, J2.2, R5.2, U2.16, U3.1, U3.3
VIN1: C6.1, C7.1, J3.2, R9.2, U4.16, U5.1, U5.3
VIN2: C11.1, C12.1, J5.2, R15.2, U7.16, U8.1, U8.3
VIN3: C16.1, C17.1, J7.2, R21.2, U10.16, U11.1, U11.3
VIN4: C21.1, C22.1, J9.2, R27.2, U13.16, U14.1, U14.3
VIN5: C26.1, C27.1, J11.2, R33.2, U16.16, U17.1, U17.3

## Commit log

2018-12-18 Change to SD from SPI flash
    [LCD_TFT_Breakout_1in8_128x160.brd, LCD_TFT_Breakout_1in8_128x160.sch]
2018-12-19 Move old checklist reports to folder
    [dec17_Board_Design_Checklist_SparkFun LCD TFT Breakout 1.8in_(128x160)_V10.xls]
2018-12-19 Small fixes/tweaks according to checklist
    [LCD_TFT_Breakout_1in8_128x160.brd, LCD_TFT_Breakout_1in8_128x160.sch]
2018-12-19 Create new checklist report
    [Board_Design_Checklist_LCD_TFT_Breakout-1.8in_(128x160)_v10.xls]
2018-12-19 Improve ground plane continuity
    [LCD_TFT_Breakout_1in8_128x160.brd]
2018-12-20 Perform Proto Review task items
    Completes and closes issue #1
    [LCD_TFT_Breakout_1in8_128x160.brd, LCD_TFT_Breakout_1in8_128x160.sch]
2018-12-21 Perform checklist after proto review
    [LCD_TFT_Breakout_1in8_128x160.brd, LCD_TFT_Breakout_1in8_128x160.sch, TFT_LCD_Breakout_1in8_Board_Design_Checklist.ods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]
2018-12-21 Panelize and CAM prototypes
    [LCD_TFT_Breakout_1in8_128x160-Panel.GBL, LCD_TFT_Breakout_1in8_128x160-Panel.GBO, LCD_TFT_Breakout_1in8_128x160-Panel.GBS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]
2019-01-02 Fix silkscreen and bump out SD card 50 mil
    [LCD_TFT_Breakout_1in8_128x160.brd]
2019-01-02 Reduce strain on FPC cable
    Acheived by moving the connector toward the PTH row by 40 mil. Route out area moved flush with v-score and also narrowed a little bit
    [LCD_TFT_Breakout_1in8_128x160.brd]
2019-01-02 Minor touch-ups (trace routing, silk placement etc)
    [LCD_TFT_Breakout_1in8_128x160.brd]
2019-01-03 Fixed Reds Design Review Issues
    As shown in isse #2
    - Offset route-out from v-score
    - Added FPC numbers in silk
    - Additional little silk rearrangements/tweaking
    [LCD_TFT_Breakout_1in8_128x160.brd, LCD_TFT_Breakout_1in8_128x160.sch]
2019-01-03 Make output connector look prettier in schematic
    [LCD_TFT_Breakout_1in8_128x160.sch]
2019-01-03 Update version to v10
    [LCD_TFT_Breakout_1in8_128x160.brd, LCD_TFT_Breakout_1in8_128x160.sch]
2019-01-03 Remove wire stubs
    [LCD_TFT_Breakout_1in8_128x160.brd]
2019-01-03 Finished checklist after design review
    [Board_Design_Checklist.xls, Jan3_Board_Design_Checklist.xls, LCD_TFT_Breakout_1in8_128x160.brd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]
2019-01-03 Address issue #3
    Removed unnecessary via on cs line
    Linked via under SD socket to GND net
    Cleared one wire stub DRC error and approved remaining
    [Jan3_TFT_LCD_1in8_Board_Design_Checklist.xls, LCD_TFT_Breakout_1in8_128x160.brd]
2019-01-07 Fill out README
    [LCD_TFT_Breakout_1in8_128x160.brd]
2019-01-08 Move route out to dimension layer per gerber review
    [LCD_TFT_Breakout_1in8_128x160.brd]
2019-01-08 Set DRC to fab limit
    [LCD_TFT_Breakout_1in8_128x160.brd]

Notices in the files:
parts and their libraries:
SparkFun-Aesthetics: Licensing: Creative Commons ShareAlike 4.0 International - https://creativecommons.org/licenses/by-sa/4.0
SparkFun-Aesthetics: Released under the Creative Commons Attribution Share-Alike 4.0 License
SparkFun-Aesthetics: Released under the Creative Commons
